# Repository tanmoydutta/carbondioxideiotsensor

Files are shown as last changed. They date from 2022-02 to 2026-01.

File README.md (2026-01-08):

Cyllene is an IoT module for Carbon di Oxide concentration detection. It is based on SCD-41 CO2 sensor from Sensirion. The core controller is an ESP32 D4 Pico for WiFi and Bluetooth/BLE connectivity. Features include - 
- Carbon-di-Oxide sensor
- WiFi and Bluetooth/BLE connectivity
- Onboard antenna
- Programmable using onboard USB UART interface
- USB Type C connector
- USB / LiPo Battery powered (Optional)
- Onboard LiPo charger (Optional)

This is a conceptual view of the new enclosure for mounting on a whiteboard -
<p align="center">
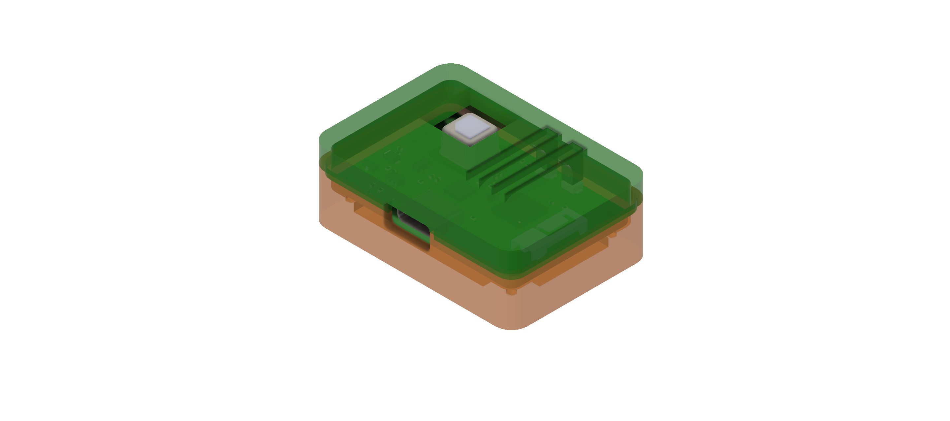
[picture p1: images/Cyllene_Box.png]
Cyllene 3D
  
</p>

<p align="center">
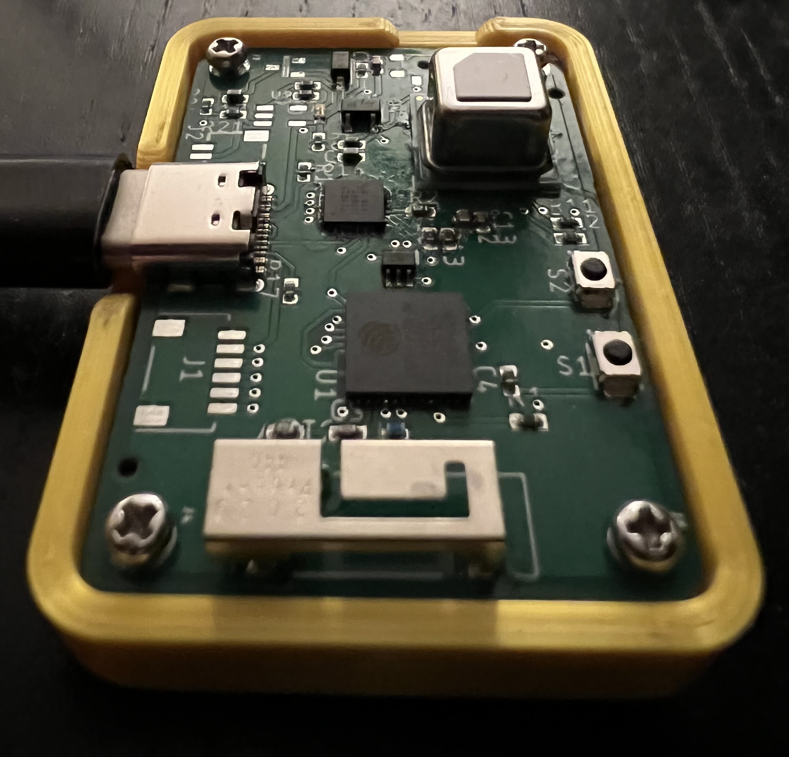
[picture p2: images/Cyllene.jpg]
Cyllene
  
</p>

This project is certified for Open Source Hardware:
<p align="center">
  <a href="https://certification.oshwa.org/nl000007.html">
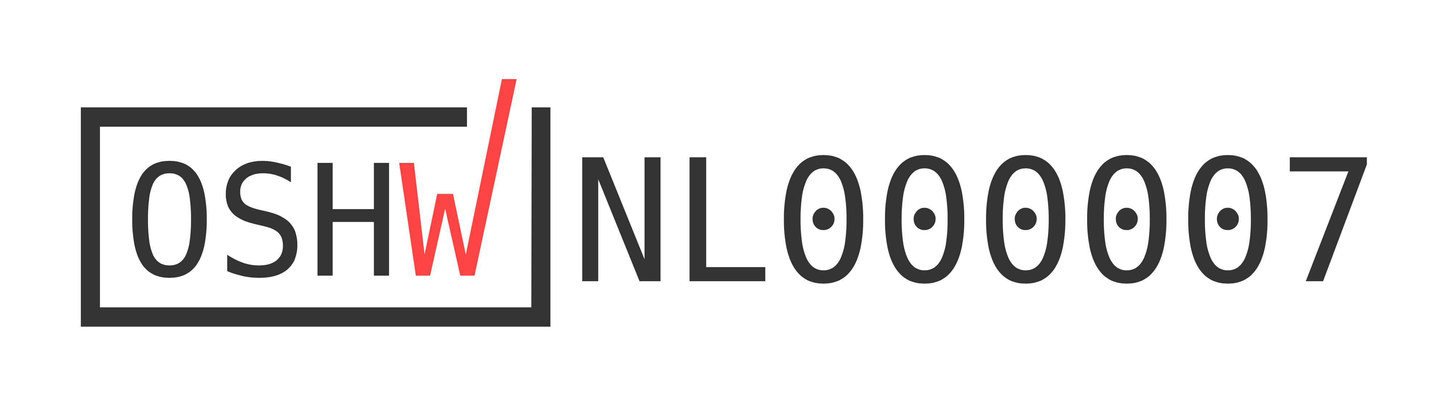
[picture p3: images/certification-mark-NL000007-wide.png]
OSHWA OSHWA Certification
    
  </a>
</p>



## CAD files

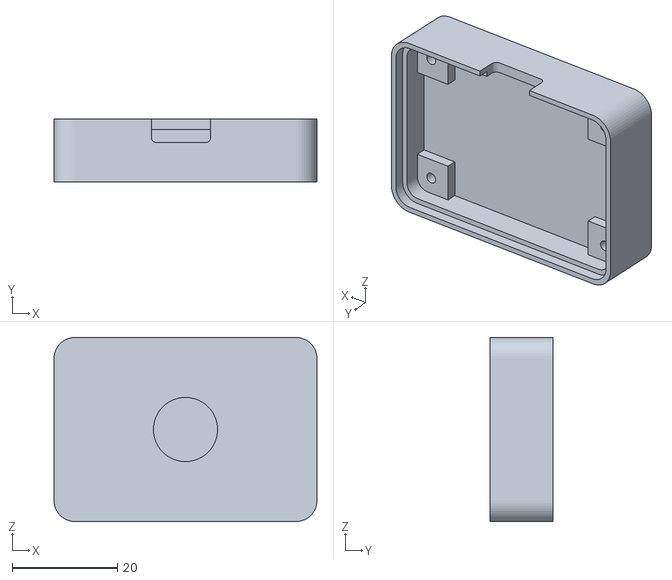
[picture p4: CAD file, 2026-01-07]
3D_files/Cyllene_Bot.stl
50.0 x 12.0 x 35.0

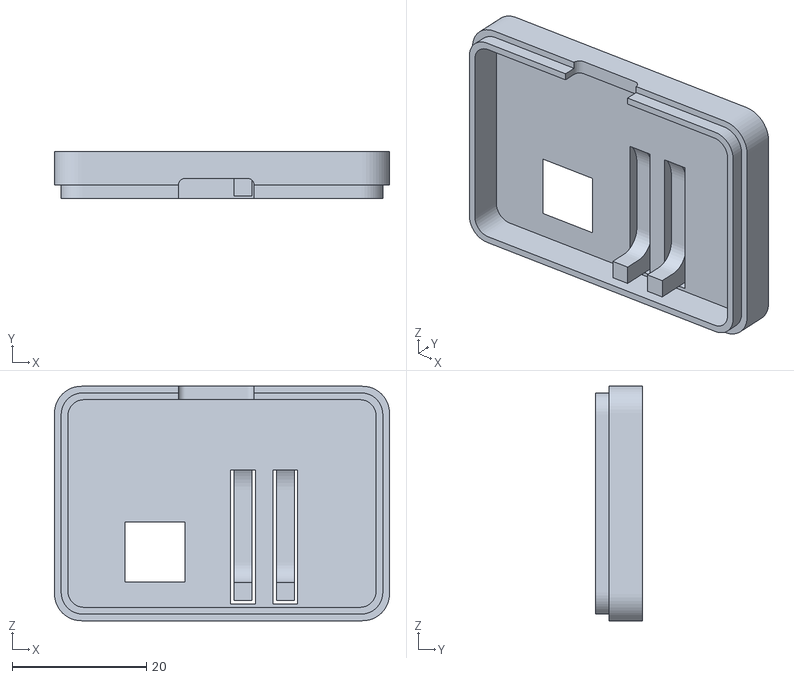
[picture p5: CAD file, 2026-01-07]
3D_files/Cyllene_Top.stl
50.0 x 7.00 x 35.0

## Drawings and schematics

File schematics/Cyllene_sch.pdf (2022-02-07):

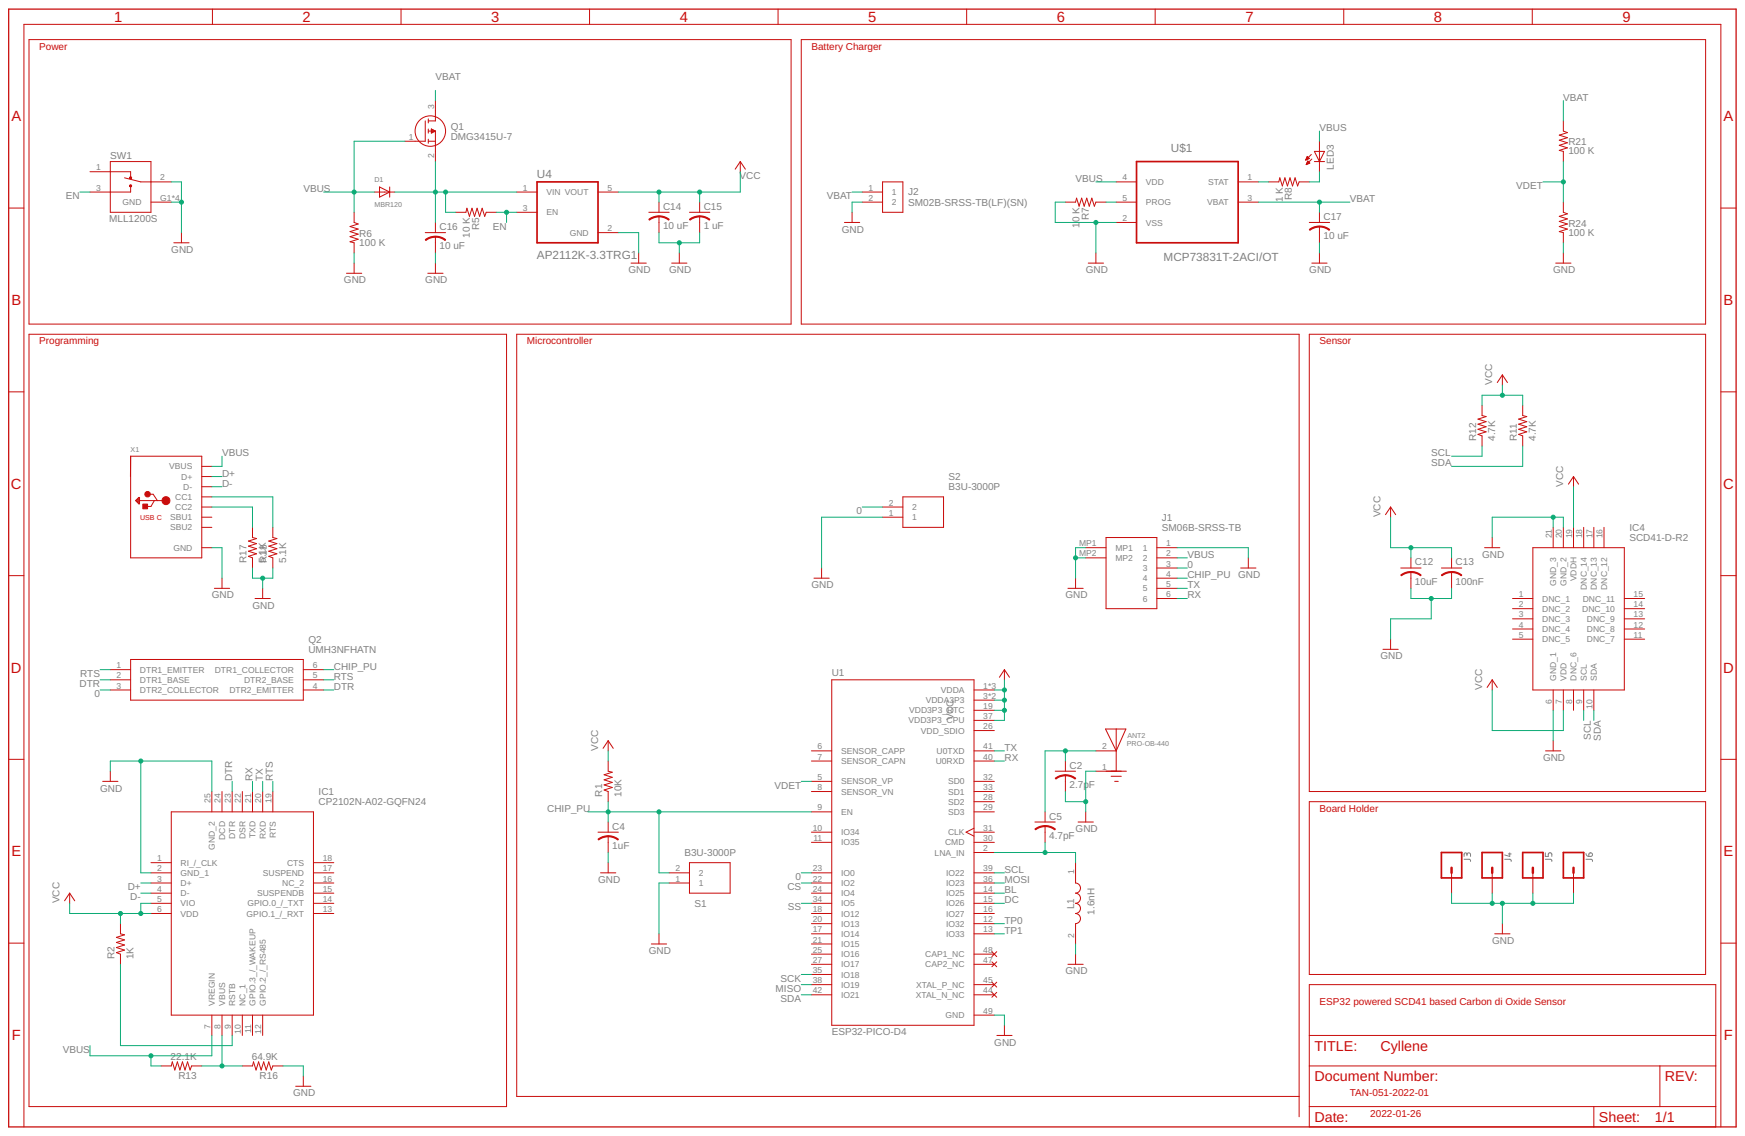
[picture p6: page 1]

ESP32 powered SCD41 based Carbon di Oxide Sensor

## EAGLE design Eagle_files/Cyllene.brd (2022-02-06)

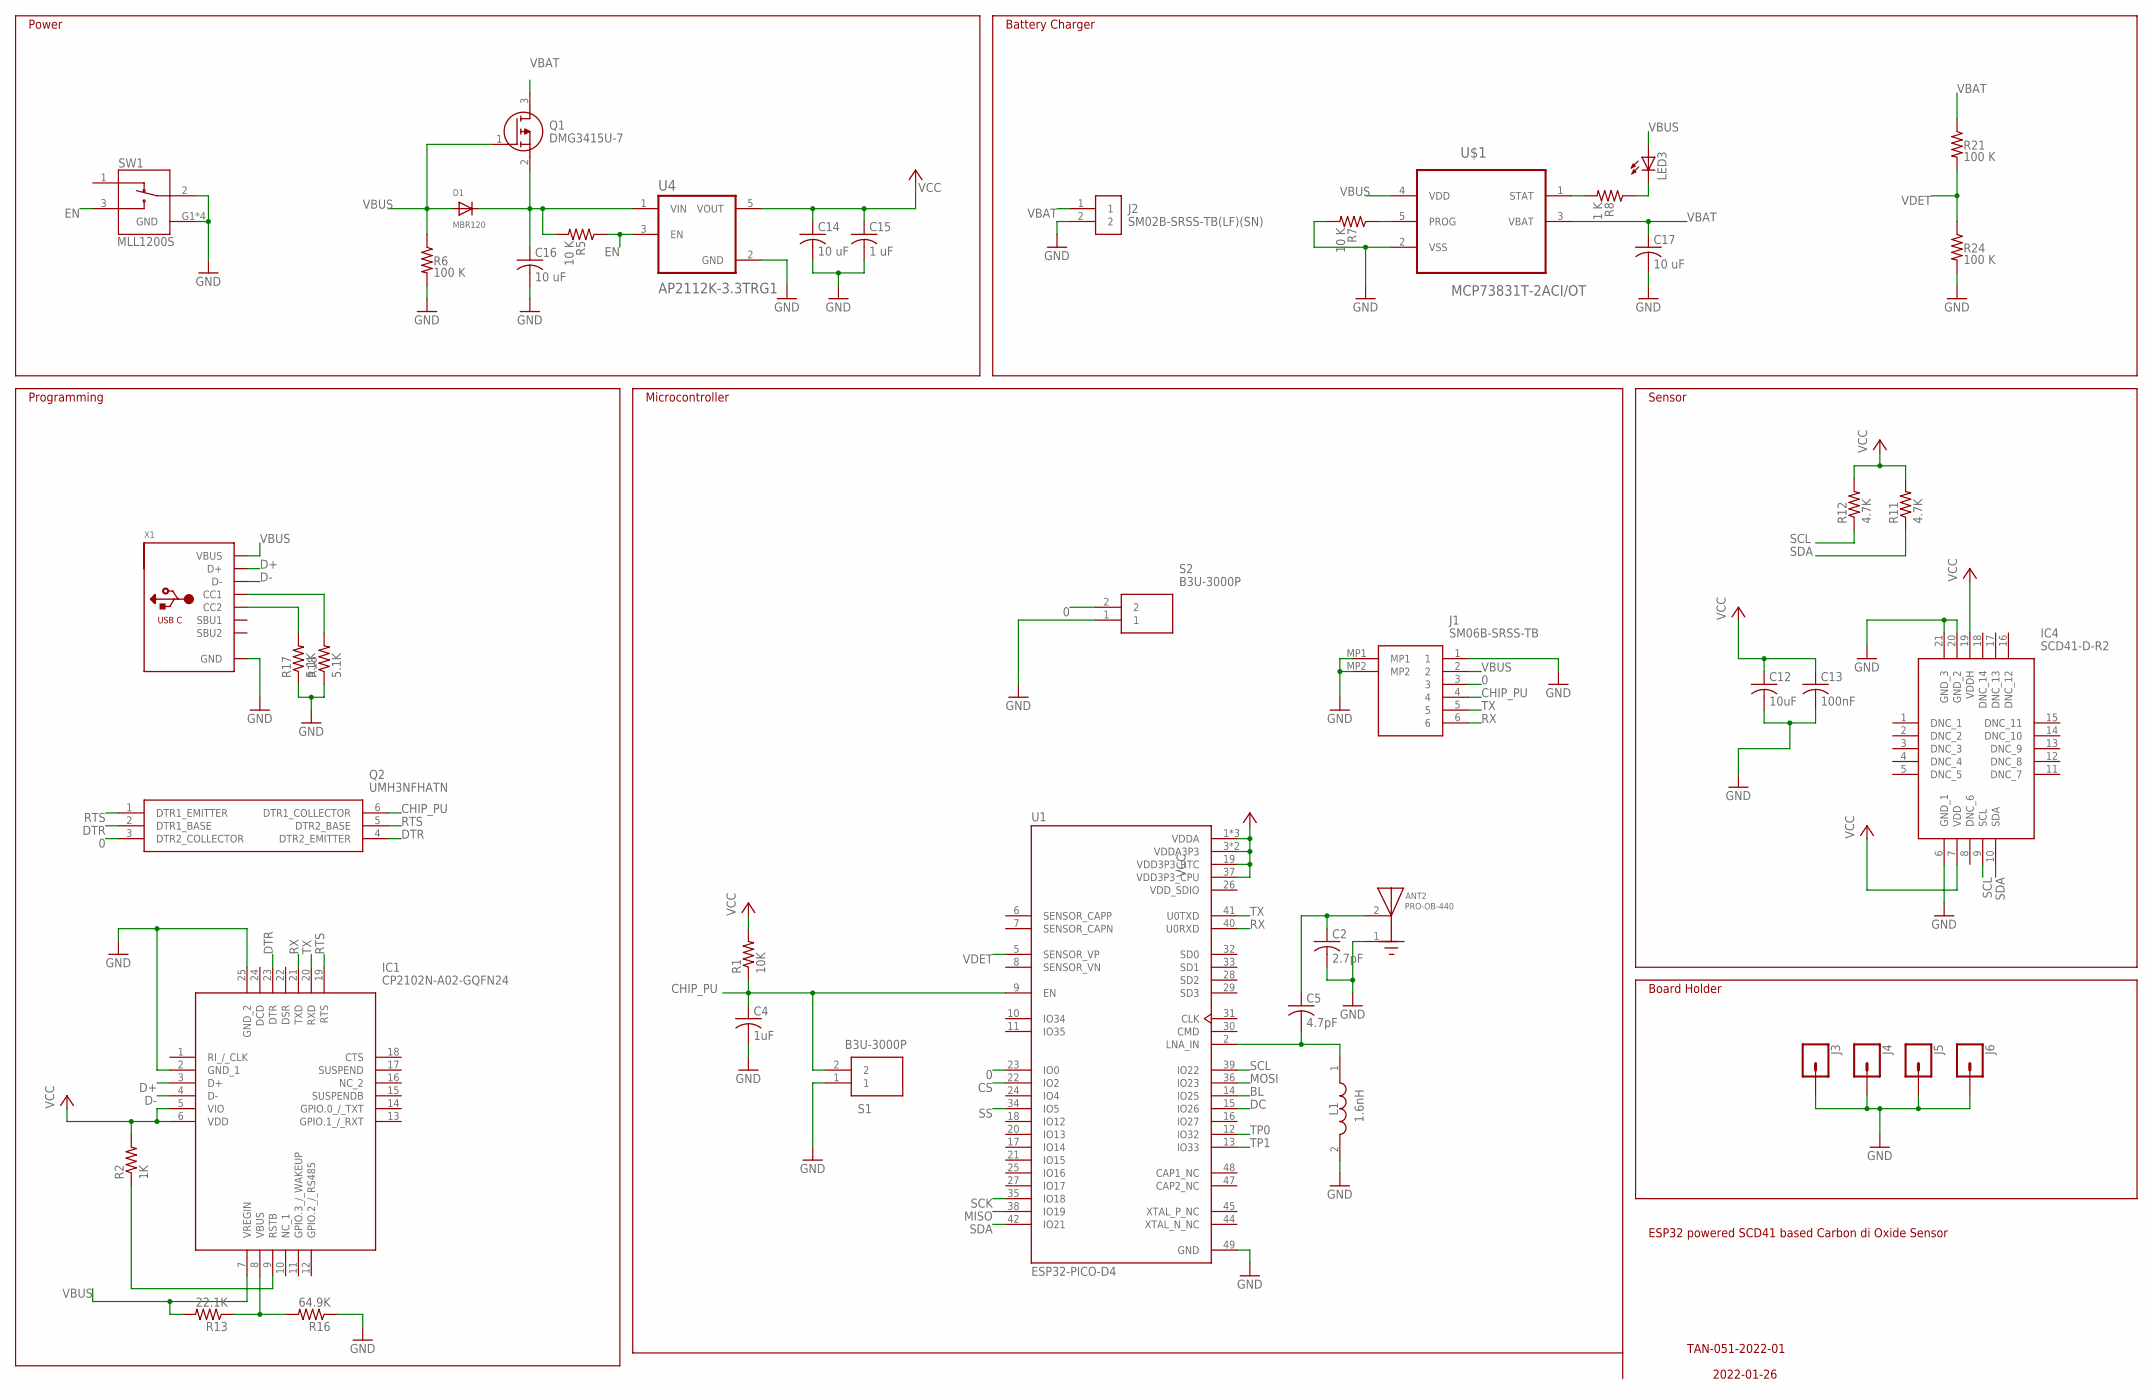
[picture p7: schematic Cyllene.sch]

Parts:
ANT2: PRO-OB-440; ANT_PRO-OB-440
C2: 2.7pF; C0402
C4: 1uF; C0402
C5: 4.7pF; C0402
C12: 10uF; C0402
C13: 100nF; C0402
C14, C16, C17: 10 uF; C0402
C15: 1 uF; C0402
D1: MBR120; SOD-123
IC1: CP2102N-A02-GQFN24; QFN50P400X400X80-25N
IC4: SCD41-D-R2; SCD41DR2
J1: SM06B-SRSS-TB; SM06BSRSSTB
J2: SM02B-SRSS-TB(LF)(SN)
J3, J4, J5, J6: CONN_01PTH_2MM; 1X01_2MM
L1: 1.6nH; LQW15CNR20J00B
LED3: LEDCHIPLED_0603; CHIPLED_0603
Q1: DMG3415U-7; SOT96P240X100-3N
Q2: UMH3NFHATN; SOT65P210X100-6N
R1: 10K; R0402
R2: 1K; R0402
R5, R7: 10 K; R0402
R6, R21, R24: 100 K; R0402
R8: 1 K; R0402
R11, R12: 4.7K; R0402
R13: 22.1K; R0402
R16: 64.9K; R0402
R17, R18: 5.1K; R0402
S1, S2: B3U-3000P; B3U-1000P
SW1: MLL1200S; SW_MLL1200S
U1: ESP32-PICO-D4; PQFN50P700X700X104-49N
U4: AP2112K-3.3TRG1; SOT95P285X140-5N
U$1: MCP73831T-2ACI/OT; SOT95P280X145-5N
X1: MICROBUILDER_USB_C; MICROBUILDER_USB_C_CUSB31-CFM2AX-01-X

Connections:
0: J1.3, Q2.3 (DTR2_COLLECTOR), S2.2, U1.23 (IO0)
BL: U1.14 (IO25)
CHIP_PU: C4.1, J1.4, Q2.6 (DTR1_COLLECTOR), R1.1, S1.2, U1.9 (EN)
CS: U1.22 (IO2)
D+: IC1.3 (D+), X1.A6 (D+), X1.B6 (D+)
D-: IC1.4 (D-), X1.A7 (D-), X1.B7 (D-)
DC: U1.15 (IO26)
DTR: IC1.23 (DTR), Q2.2 (DTR1_BASE), Q2.4 (DTR2_EMITTER)
EN: R5.1, SW1.3, U4.3 (EN)
GND: ANT2.1 (GND), C2.2, C4.2, C12.2, C13.2, C14.2, C15.2, C16.2, C17.2, IC1.2 (GND_1), IC1.25 (GND_2), IC4.6 (GND_1), IC4.20 (GND_2), IC4.21 (GND_3), J1.1, J1.MP1, J1.MP2, J2.2, J3.1, J4.1, J5.1, J6.1, L1.2, R6.2, R7.2, R16.1, R17.1, R18.1, R24.2, S1.1, S2.1, SW1.2, SW1.G1 (GND), SW1.G2 (GND), SW1.G3 (GND), SW1.G4 (GND), U1.49 (GND), U4.2 (GND), U$1.2 (VSS), X1.A1B12 (GND), X1.B1A12 (GND)
MISO: U1.38 (IO19)
MOSI: U1.36 (IO23)
unnamed: C5.2, L1.1, U1.2 (LNA_IN)
unnamed: ANT2.2 (FEED), C2.1, C5.1
unnamed: C16.1, D1.C, Q1.2 (S), R5.2, U4.1 (VIN)
unnamed: IC1.9 (RSTB), R2.1
unnamed: IC1.8 (VBUS), R13.1, R16.2
unnamed: R18.2, X1.A5 (CC1)
unnamed: R17.2, X1.B5 (CC2)
unnamed: R8.2, U$1.1 (STAT)
unnamed: R7.1, U$1.5 (PROG)
unnamed: LED3.C, R8.1
RTS: IC1.19 (RTS), Q2.1 (DTR1_EMITTER), Q2.5 (DTR2_BASE)
RX: IC1.21 (TXD), J1.6, U1.40 (U0RXD)
SCK: U1.35 (IO18)
SCL: IC4.9 (SCL), R12.1, U1.39 (IO22)
SDA: IC4.10 (SDA), R11.1, U1.42 (IO21)
SS: U1.34 (IO5)
TP0: U1.12 (IO32)
TP1: U1.13 (IO33)
TX: IC1.20 (RXD), J1.5, U1.41 (U0TXD)
VBAT: C17.1, J2.1, Q1.3 (D), R21.1, U$1.3 (VBAT)
VBUS: D1.A, IC1.7 (VREGIN), J1.2, LED3.A, Q1.1 (G), R6.1, R13.2, U$1.4 (VDD), X1.A4B9 (VBUS), X1.B4A9 (VBUS)
VCC: C12.1, C13.1, C14.1, C15.1, IC1.5 (VIO), IC1.6 (VDD), IC4.7 (VDD), IC4.19 (VDDH), R1.2, R2.2, R11.2, R12.2, U1.1 (VDDA), U1.3 (VDDA3P3), U1.4 (VDDA3P3), U1.19 (VDD3P3_RTC), U1.37 (VDD3P3_CPU), U1.43 (VDDA), U1.46 (VDDA), U4.5 (VOUT)
VDD_SDIO: U1.26 (VDD_SDIO)
VDET: R21.2, R24.1, U1.5 (SENSOR_VP)

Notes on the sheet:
Power
Microcontroller
Battery Charger
Programming
Board Holder
Sensor
ESP32 powered SCD41 based Carbon di Oxide Sensor
TAN-051-2022-01
2022-01-26

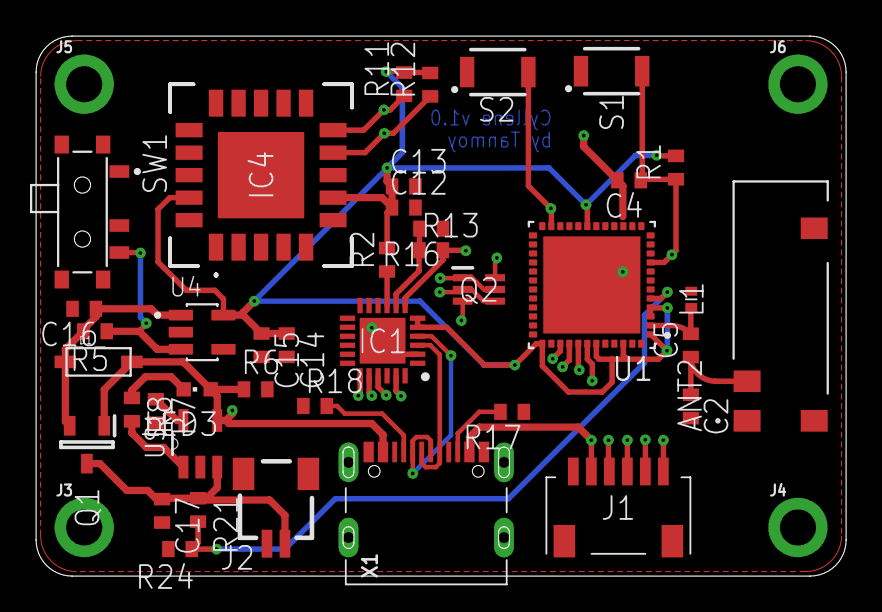
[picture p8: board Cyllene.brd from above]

Board: 4 copper layers, 45.0 x 30.0 mm, 44 parts (0 on the bottom side), 26 nets.

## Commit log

2022-02-06 Eagle CAD files for sensors
    [Cyllene.brd, Cyllene.sch]
2022-02-07 Update to documentation
    [Cyllene.sch]
2026-01-07 Restructuring and enriching the content of this repo
    [Cyllene.brd, Cyllene.sch, Cyllene_Bot.stl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]
2026-01-08 Revise README for Cyllene IoT module details
    Updated the description of the Cyllene IoT module and made features optional. Added conceptual images for the new enclosure.

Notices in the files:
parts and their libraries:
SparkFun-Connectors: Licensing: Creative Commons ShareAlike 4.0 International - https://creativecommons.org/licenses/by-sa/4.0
